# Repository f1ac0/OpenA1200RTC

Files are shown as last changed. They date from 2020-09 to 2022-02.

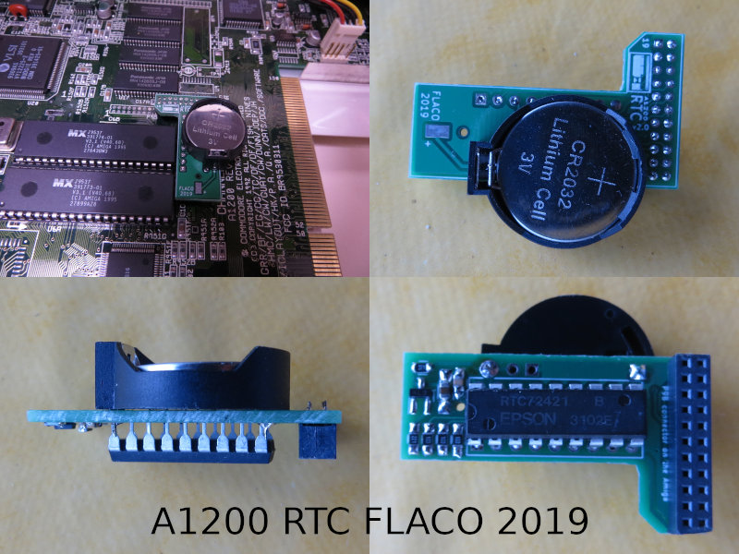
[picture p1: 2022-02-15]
OpenA1200RTC FLACO 2019.JPG

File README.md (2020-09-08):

# OpenA1200RTC
OpenA1200RTC is an Open Hardware RTC module for the Amiga 1200 by screwbreaker and Sukkopera : https://github.com/screwbreaker/OpenA1200RTC.

This project is a different layout of the board, with almost the same BOM :
- shorter pin header,
- no jumper to disable the board,
- footprint for CR1220 and wired cell in addition to the CR2032.

# Disclaimer
This is a hobbyist project, it comes with no warranty and no support.

I publish this work using the same license as the original project : "Open Hardware. If you make any modifications to the board, please contribute them back".

If you find it useful, please reward the original authors.

# BOM
- 1x RTC62421
- 1x 2x11 2.0mm pin socket
- 1x 2.2uF 0805 capacitor
- 1x 100nF 0805 capacitor
- 1x BAT721C or BAT54C diodes
- 2x 220 ohm 0805 resistor
- 3x 10k ohm 0805 resistor
- 1x battery holder : CR1220, CR2032 or pin header

# Making it
Make sure that the chip is working before soldering it.

If you plan to use a battery holder, make sure that the RTC62421 is not fully inserted and that its leads and your solder joints do not stick out of the holes in PCB. Thanks to this, the holder will be able to lay flat on the PCB.

Check for shorts at least between 5V and GND traces before applying power !

# Using it
- Install the battery,
- Plug on the motherboard,
- Power on the system.

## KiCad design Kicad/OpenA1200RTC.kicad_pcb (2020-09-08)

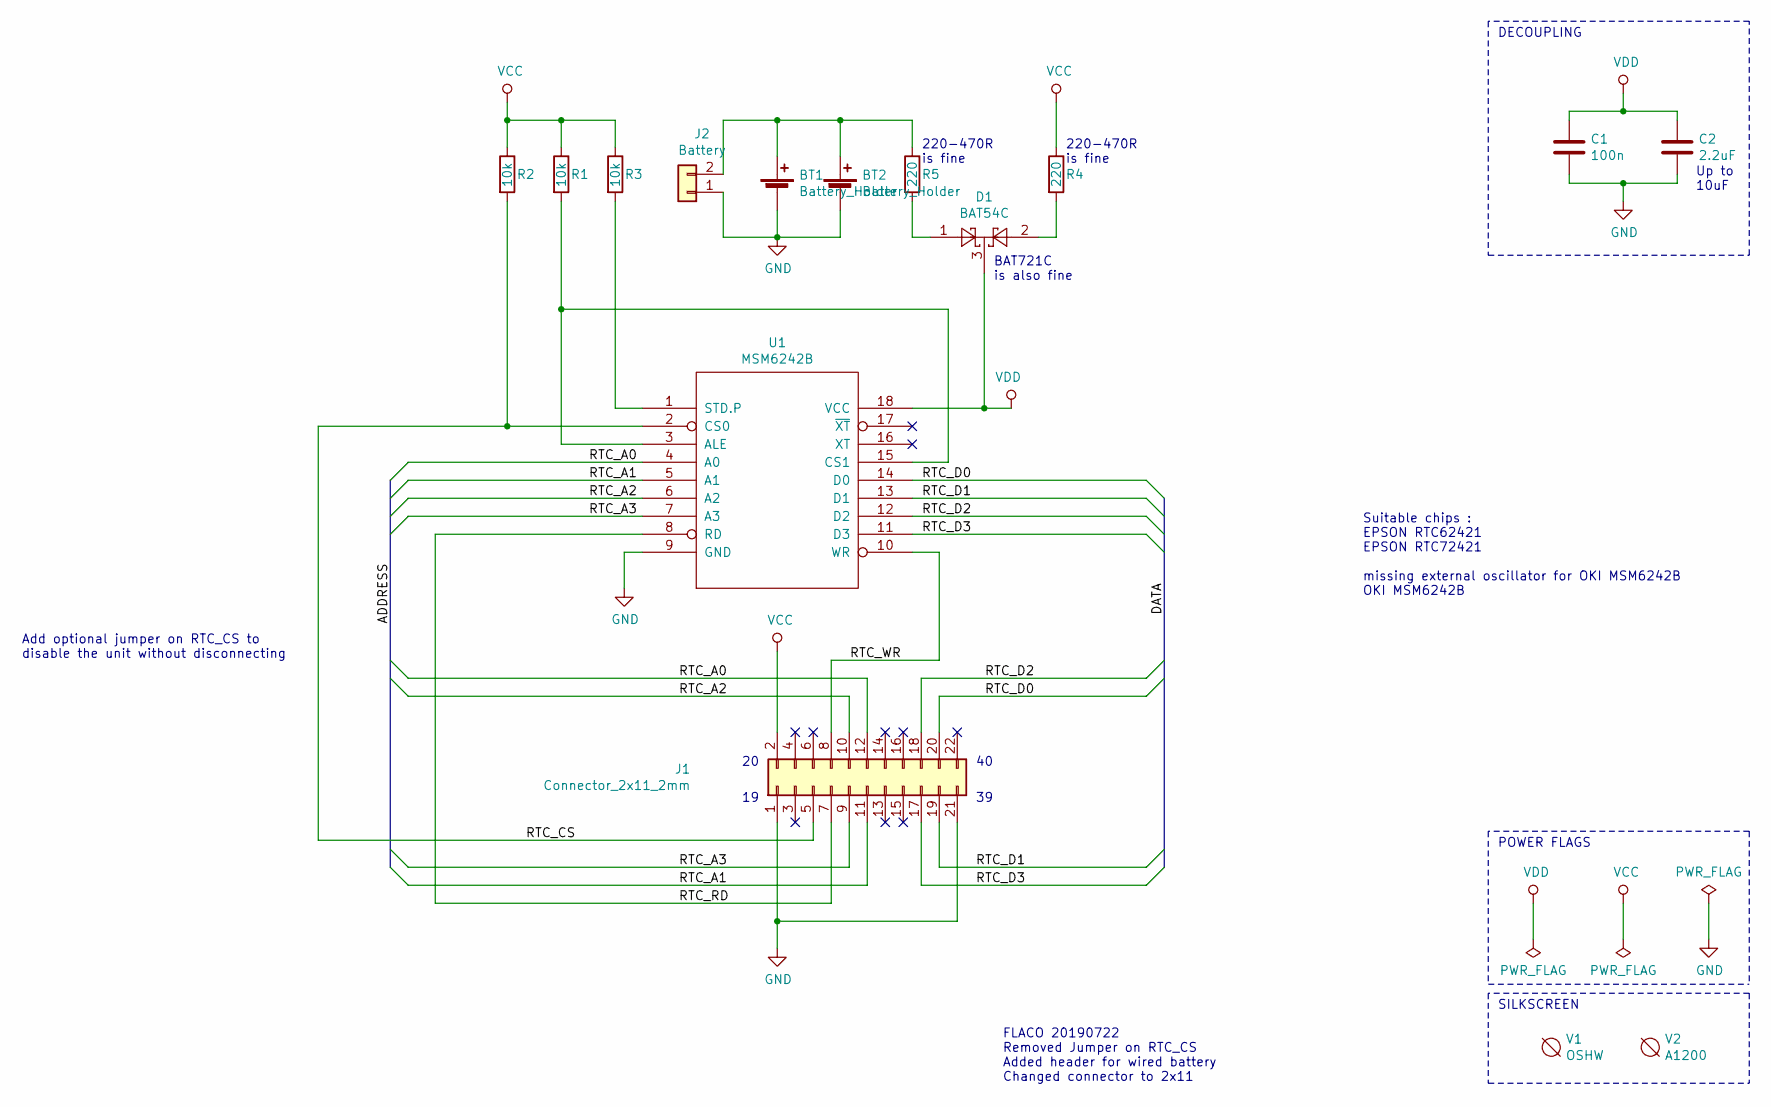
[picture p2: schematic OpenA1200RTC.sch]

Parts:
BT1: Battery_Holder; Battery_Holder_Coin_2032_BS-7
BT2: Battery_Holder; Battery_Holder_Coin_1220_BS-1220-1
C1: 100n; C_0805_HandSoldering
C2: 2.2uF; C_1206_HandSoldering
D1: BAT54C; SOT-23_Handsoldering
J1: Connector_2x11_2mm; Socket_Strip_Straight_2x11_Pitch2.00mm
J2: Battery; Pin_Header_Straight_1x02_Pitch2.54mm
R1, R2, R3: 10k; R_0805_HandSoldering
R4: 220; R_0805_HandSoldering
R5: 220; R_0805
U1: MSM6242B; DIP-18_W7.62mm_Socket
V1: OSHW; OSHW-Logo_5.7x6mm_SilkScreen
V2: A1200

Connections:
/RTC_A0: J1.12, U1.4 (A0)
/RTC_A1: J1.11, U1.5 (A1)
/RTC_A2: J1.10, U1.6 (A2)
/RTC_A3: J1.9, U1.7 (A3)
/RTC_CS: J1.5, R2.2, U1.2 (CS0)
/RTC_D0: J1.20, U1.14 (D0)
/RTC_D1: J1.19, U1.13 (D1)
/RTC_D2: J1.18, U1.12 (D2)
/RTC_D3: J1.17, U1.11 (D3)
/RTC_RD: J1.7, U1.8 (RD)
/RTC_WR: J1.8, U1.10 (WR)
GND: BT1.2 (-), BT2.2 (-), C1.2, C2.2, J1.1, J1.21, J2.1, U1.9 (GND)
unnamed: BT1.1 (+), BT2.1 (+), J2.2, R5.1
unnamed: D1.1, R5.2
unnamed: D1.2, R4.2
unnamed: R1.2, U1.3 (ALE), U1.15 (CS1)
unnamed: R3.2, U1.1 (STD.P)
VCC: J1.2, R1.1, R2.1, R3.1, R4.1
VDD: C1.1, C2.1, D1.3, U1.18 (VCC)

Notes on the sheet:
DECOUPLING
POWER FLAGS
Up to 10uF
SILKSCREEN
220-470R is fine
BAT721C is also fine
Add optional jumper on RTC_CS to disable the unit without disconnecting
Suitable chips : EPSON RTC62421 EPSON RTC72421 missing external oscillator for OKI MSM6242B OKI MSM6242B
FLACO 20190722 Removed Jumper on RTC_CS Added header for wired battery Changed connector to 2x11

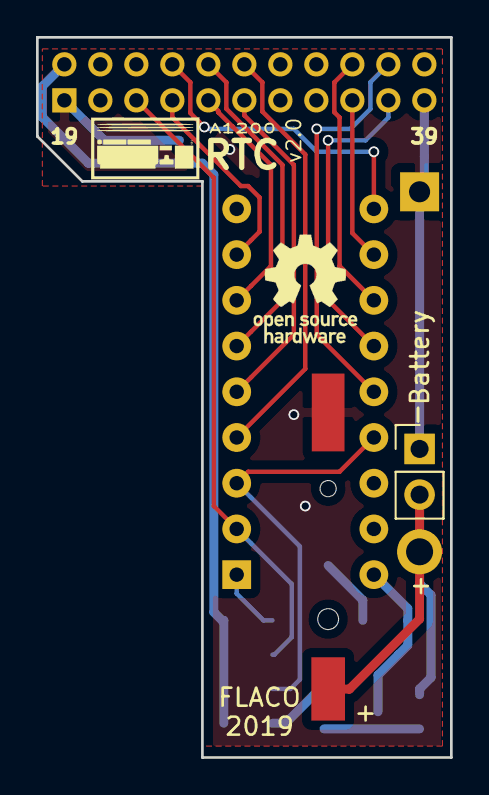
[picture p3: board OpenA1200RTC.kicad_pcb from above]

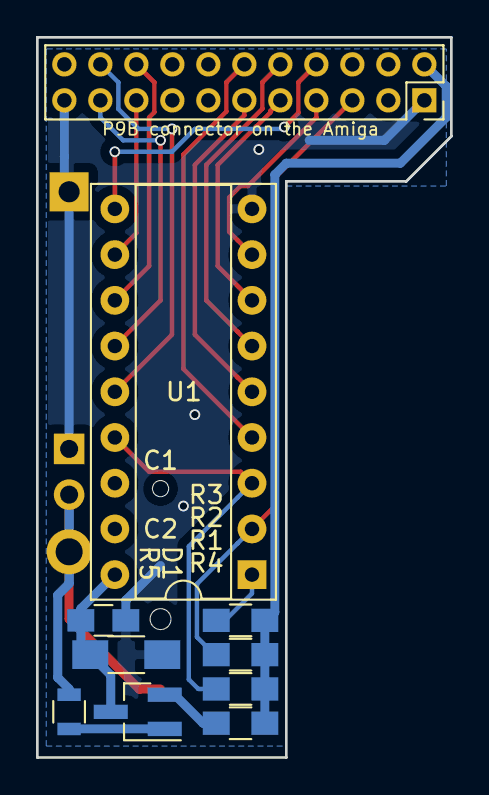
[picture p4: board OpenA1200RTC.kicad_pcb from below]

Board: 2 copper layers, 23.0 x 40.0 mm, 15 parts (10 on the bottom side), 19 nets.
